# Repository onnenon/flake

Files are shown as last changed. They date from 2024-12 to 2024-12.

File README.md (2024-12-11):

<div align="center">
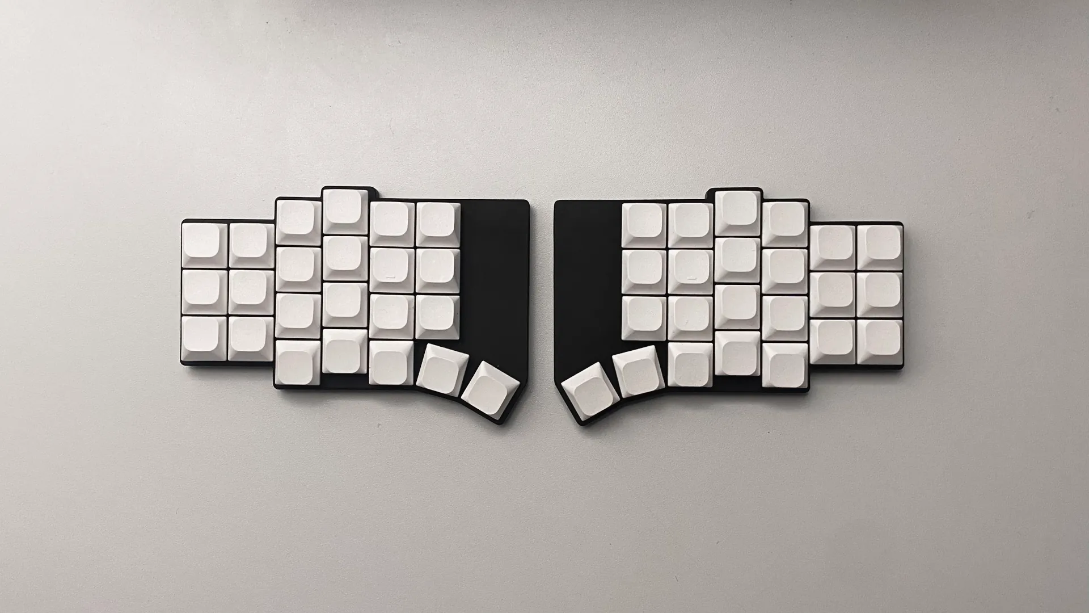
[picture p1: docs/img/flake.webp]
flake image
    
    <h3>Anywhy Flake</h3>
    <p><i>Minimalism, efficiency and comfort</i></p>
</div>

# Why

_To be productive, stay healthy and enjoy the process._

By the 19th century, a need for a faster way of writing had emerged, which led to the invention of typewriters. Two centuries later, modern keyboards don't look much different from their predecessors, even though such design has been proven to be quite inefficient and often harmful.

Addressing these problems leads to huge benefits considering how often people use keyboards in the modern world.

# How

There are several problems that the Flake keyboard solves. I'll describe those with the most significant impact.

## Stagger

If you take your hand and look at the fingers, you can notice that they are positioned horizontally. Now take a look at your keyboard - the keys are grouped in arrays that are shifted vertically, known as row-based stagger.

row-based stagger keyboard image

This well-known layout forces your fingers to move in a counterintuitive way. The solution to that problem is simple: we need to rearrange the keys in a more human-friendly way.

flake stagger image

As you can see, Flake has what's called a column-based stagger. Because of this, keys are located in the path of natural finger movement, which results in a much more pleasant typing experience and reduced fatigue.

## Split

One of the most noticeable things about Flake is that it has two separate halves.

Regular keyboards are made in a single monolithic block, and the main problem is that such a form factor requires our forearms to meet in the center. To compensate for this, wrists are bent apart. This position creates an unnatural angle between the forearm and the wrist, which in the long term will likely lead to constant wrist pain.

Each half of the split keyboard can be rotated and placed in any suitable way so everyone can adapt the setup to their personal preference, avoiding potential damage to the wrists.

As an added bonus, we get free space right between the halves which can be occupied by a trackpad, coffee, or even a cat (=^..^=).

## Keys amount

There's a high chance that some might feel confused seeing such a small number of keys, considering user productivity is one of the priorities for Anywhy.

flake s image

Indeed, Flake has fewer keys than most conventional keyboards (46 keys in total), and that's not a compromise, but a feature. A large number of keys causes hands to move around to reach further-placed keys like digits, brackets, punctuation, Backspace, Escape, etc.

Having fewer keys doesn't mean less functionality. In fact, Flake is not only fully input-compatible with regular keyboards but also allows you to add more keys than most keyboards have.

config showcase image

By default, Flake uses [ZMK Firmware](https://zmk.dev) which provides functionality that significantly increases productivity. One of the most used features, which allows having all possible inputs with a minimal amount of keys, is [layers](https://zmk.dev/docs/keymaps#layers). They are pretty simple and work just like the well-known Shift key.

For those who strive for absolute comfort and compactness, there is also Flake S with 40 keys.

flake s image

The small version lacks one outer column on each of the halves to reduce pinky usage, as it is the weakest of all fingers.

## Thumb cluster

Keyboards are used in various ways, not only for typing text. Most popular tasks require the use of mod keys such as Control, Alt/Option, Super/Command/Win, and of course, Shift. Even though these keys are regularly used, they are placed in ridiculously inconvenient spots where only the pinky can reach them, and as we already know, it's the weakest finger.

The Flake keyboard has a so-called thumb cluster which contains 10 keys in total to address that problem. In contrast, the thumb is one of the strongest fingers and is ideal for holding mod keys.

# What

Flake supports both wired and wireless (Bluetooth) connection, which makes it perfect for both home usage with a PC or portable setup with a laptop, tablet, or even smartphone.

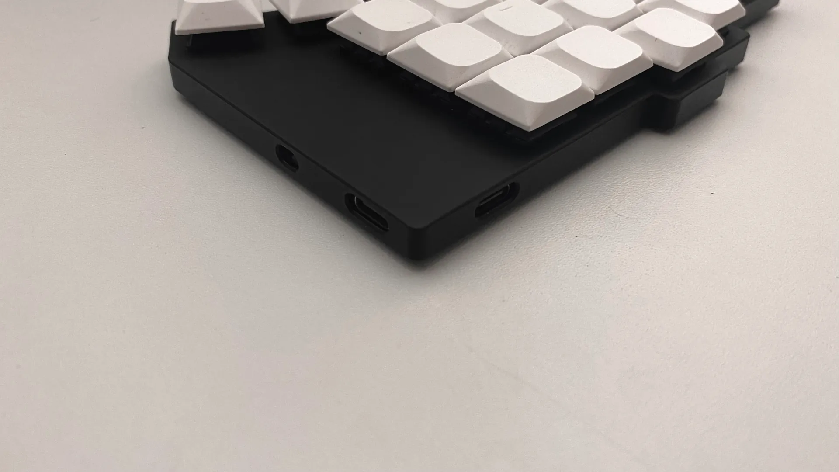
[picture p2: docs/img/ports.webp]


To achieve both types of connectivity, each half has two USB-C ports, one on the top and one on the inner side. The side port is used to connect the halves together, and then one of them (usually the left one) can be connected to any device using the top port, which is also used to charge the keyboard.

> Ports on the side are used only to communicate with each other, so they can't be used to charge the keyboard or to flash the new firmware
> 
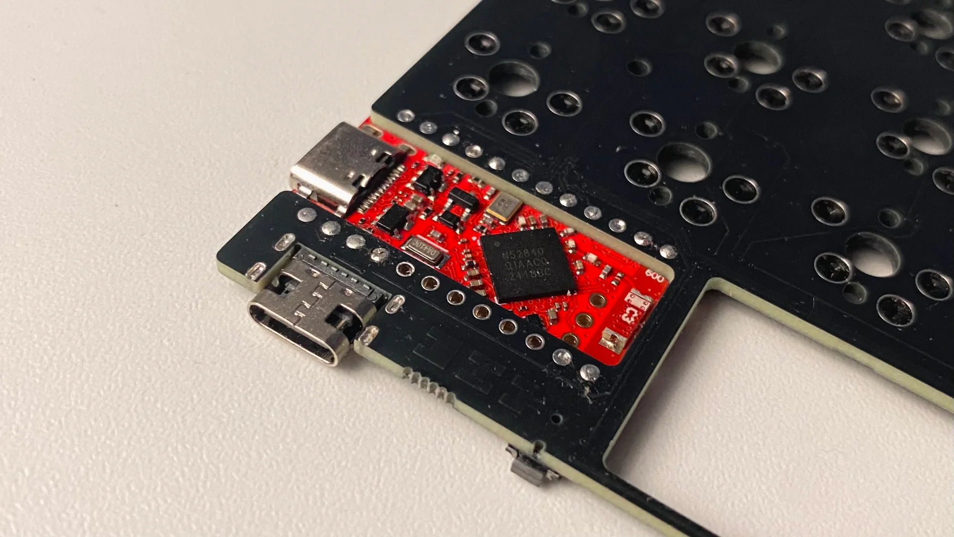
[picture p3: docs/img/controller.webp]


Flake is extremely thin. The keyboard body without switches and feet is a bit less than 0.8cm in height, which makes it compact and really comfortable to use, especially with low-profile switches.

> Unfortunately, to achieve such a low height, some tradeoffs were made in PCB and enclosure designs that make assembly and soldering a bit tricky. There's a chance that the keyboard will become thicker in the future if it will make it more robust and easier to repair.

Talking about switches, Flake is hot-swappable and supports three types of switches: the well-known Cherry MX compatible switches, low-profile Kailh Choc V1, and their newer version Choc V2.

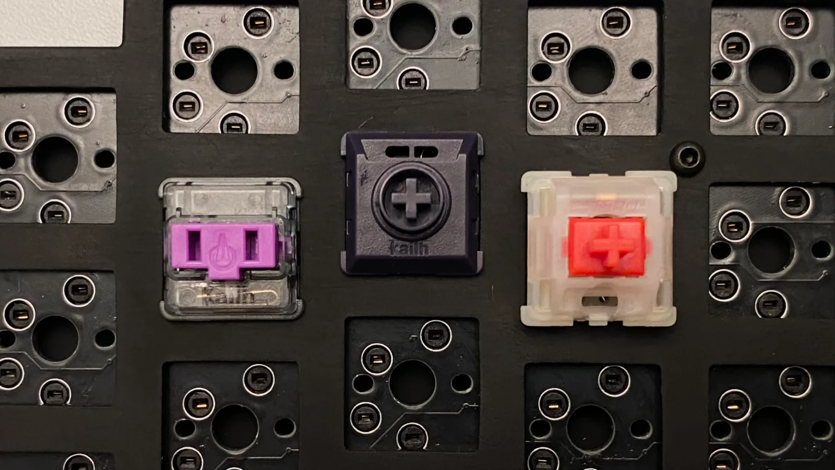
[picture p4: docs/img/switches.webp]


In order to use MX Switches, the special "plate" comes with the Flake which should be placed between the board and the switches.

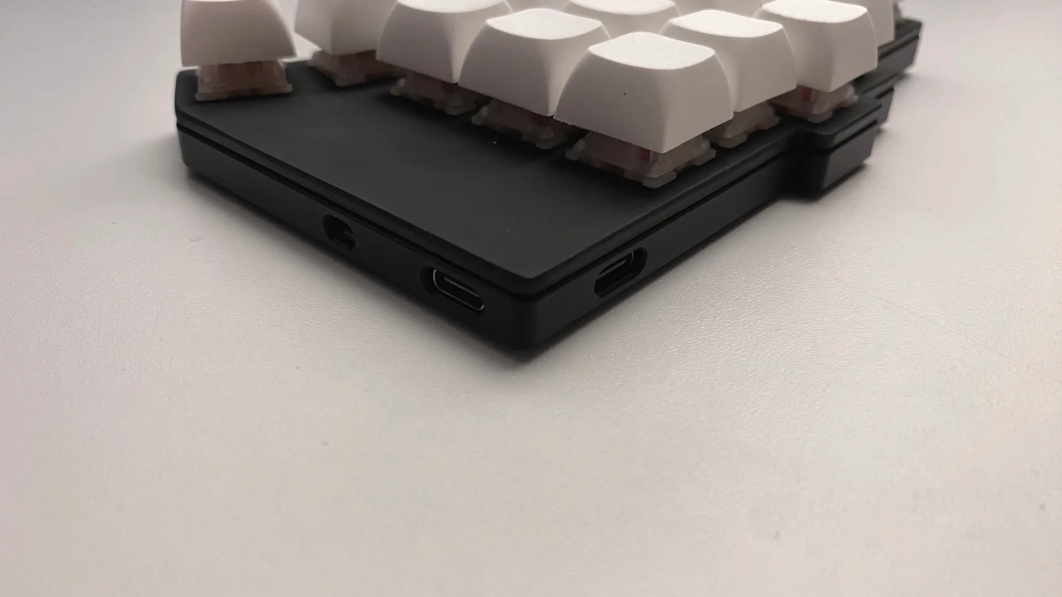
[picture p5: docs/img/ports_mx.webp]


> Plates are not required for the Choc switches as they are much lower than MX switches and don't need additional enclosure height to securely sit in the board

Anywhy Flake v0.1.0 is fully the tested version. The most similar version this repo has is v0.1.1, where I've changed the silkscreen modified some edges, and also added PCB copper fill. So if you want to build Flake yourself, I recommend using the v0.1.1 version, as well as checking out the [build guide](/docs/build_guide.md)

> Feel free to send me your builds and keyboard reviews :)

# Credits

Huge thanks to:

- [@foostan](https://github.com/foostan), the author of [Corne Keyboard](https://github.com/foostan/crkbd) which was my introduction to the world of ergonomic keyboards.
  
- [@pashutk](https://github.com/pashutk), the author of [Chocofi](https://github.com/pashutk/chocofi), an amazing tiny keyboard I've been using for a while.
  
- [@josefadamcik](https://github.com/josefadamcik), the author of [Sofle](https://github.com/josefadamcik/SofleKeyboard) which gave huge inspiration for the Flake's key layout.
  
- [@petejohanson](https://github.com/petejohanson) for creating [ZMK Firmware](https://github.com/zmkfirmware/zmk) and all the [contributors](https://github.com/zmkfirmware/zmk/graphs/contributors) that make it better each day.

- Everyone working on [KiCad](https://gitlab.com/kicad/code/kicad) and [FreeCAD](https://github.com/FreeCAD/FreeCAD), for creating such powerful open source tools

- People from the [ZMK discord server](https://zmk.dev/community/discord/invite) for being so kind while helping me learn how to design PCB and how to debug and solve various problems.

- Finally, a huge thank you to everyone who explores unpopular technologies, digs into niche topics, and makes amazing things possible.

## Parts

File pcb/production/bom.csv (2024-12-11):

Designator | Footprint | Quantity | Value | LCSC Part #
_16, _15, _14, _13, _12, _11, _10, _9, _8, _7, _6, _5, _4, _3, _2, |  | 16
BT1, BT2 | JST_1.25mm_mid-mount | 2 | Battery
D1, D10, D11, D12, D13, D14, D15, D16, D17, D18, D19, D2, D20, D21, D22, D23, D24, D25, D26, D27, D28, D29, D3, D30, D31, D32, D33, D34, D35, D36, D37, D38, D39, D4, D40, D41, D42, D43, D44, D45, D46, D5, D6, D7, D8, D9 | D_SOD-123_Handsoldering | 46 | D
J1, J2 | USB-C_6Pin_Mid-mount | 2 | USB_C_Receptacle_PowerOnly_6P
RSW1, RSW2 | TS-1289VE-4 | 2 | Reset_SW
SW1, SW10, SW11, SW12, SW13, SW14, SW15, SW16, SW17, SW18, SW19, SW2, SW20, SW21, SW22, SW23, SW24, SW25, SW26, SW27, SW28, SW29, SW3, SW30, SW31, SW32, SW33, SW34, SW35, SW36, SW37, SW38, SW39, SW4, SW40, SW41, SW42, SW43, SW44, SW45, SW46, SW5, SW6, SW7, SW8, SW9 | SW_MX_Choc-v1v2_Hotswap | 46 | SW_Push
U1, U2 | ProMicro_SMD | 2 | ProMicro

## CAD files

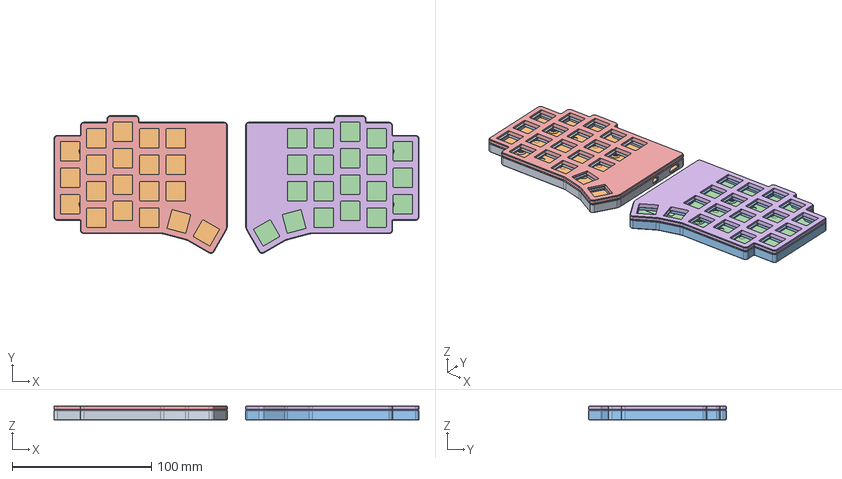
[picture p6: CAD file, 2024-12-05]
enclosure/40keys/Enclosure-S.FCStd
262.0 x 99.0 x 10.4 mm
Top
Bottom
Top-Mirrored
Bottom-Mirrored
Plate
Plate-Mirrored

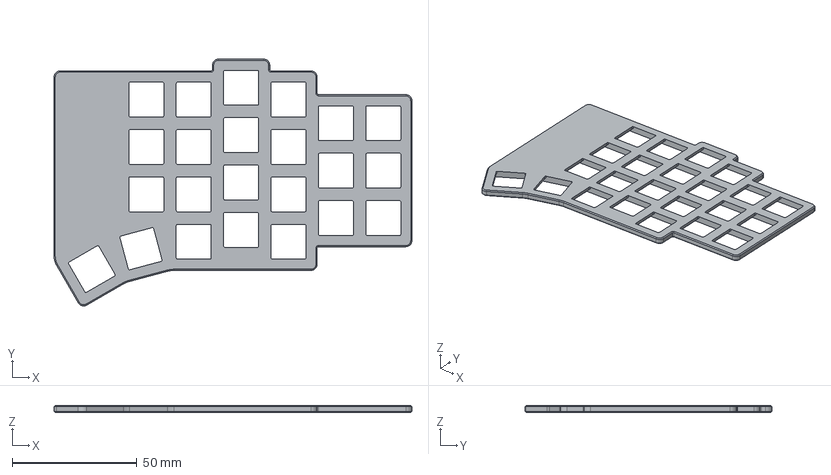
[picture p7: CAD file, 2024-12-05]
enclosure/46keys/Enclosure-Plate-Mirrored.step
143.5 x 99.0 x 3.00 mm

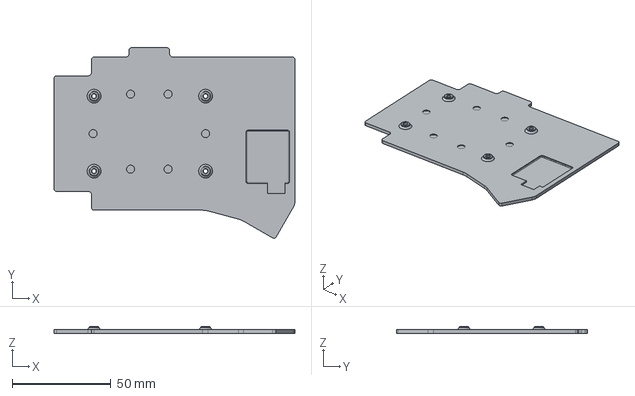
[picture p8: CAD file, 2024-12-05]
enclosure/40keys/Enclosure-S-Bottom.step
122.1 x 96.6 x 3.30 mm

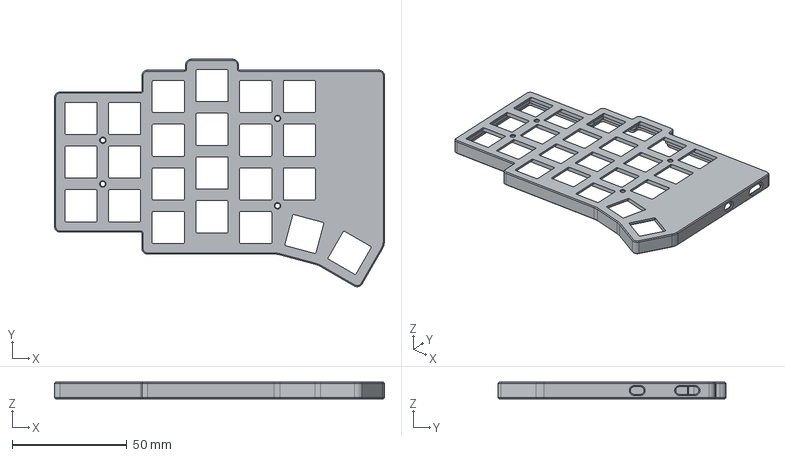
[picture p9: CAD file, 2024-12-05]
enclosure/46keys/Enclosure-Top.step
143.5 x 99.0 x 7.30 mm

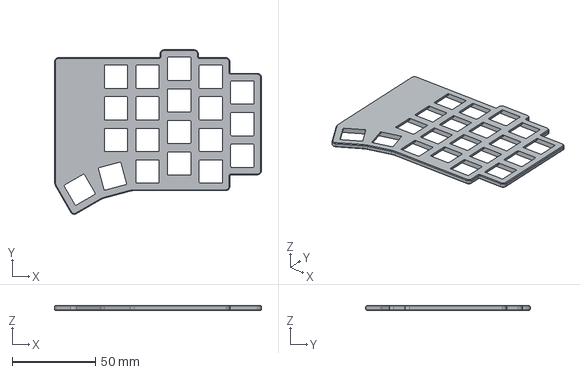
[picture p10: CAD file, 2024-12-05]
enclosure/40keys/Enclosure-S-Plate-Mirrored.step
124.5 x 99.0 x 3.00 mm

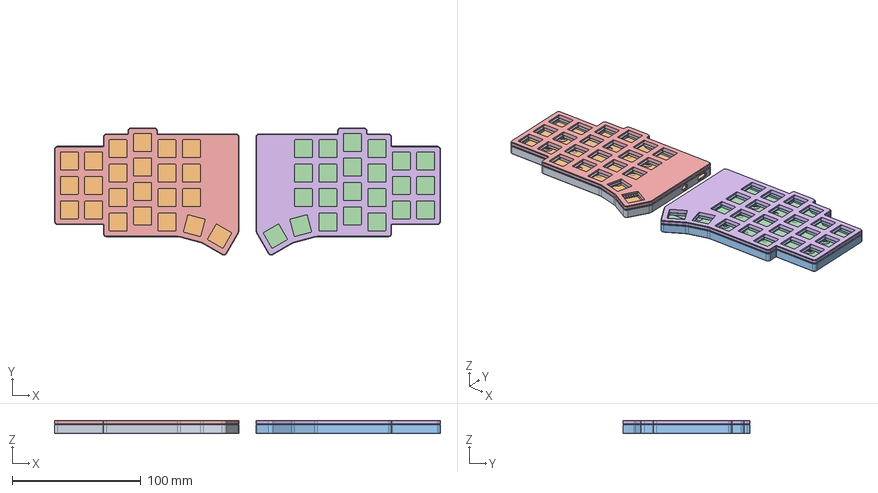
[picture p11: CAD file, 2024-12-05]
enclosure/46keys/Enclosure.FCStd
300.0 x 99.0 x 10.4 mm
Top
Bottom
Top-Mirrored
Bottom-Mirrored
Plate
Plate-Mirrored

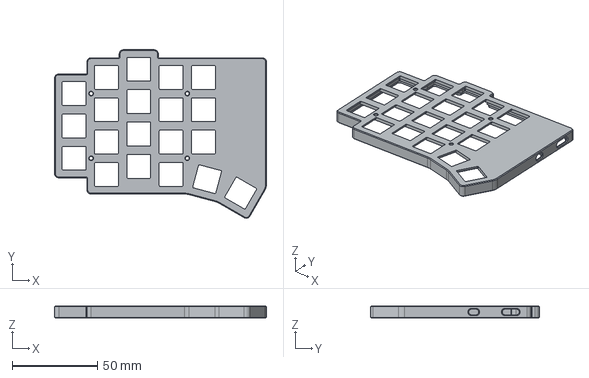
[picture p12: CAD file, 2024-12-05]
enclosure/40keys/Enclosure-S-Top.step
124.5 x 99.0 x 7.30 mm

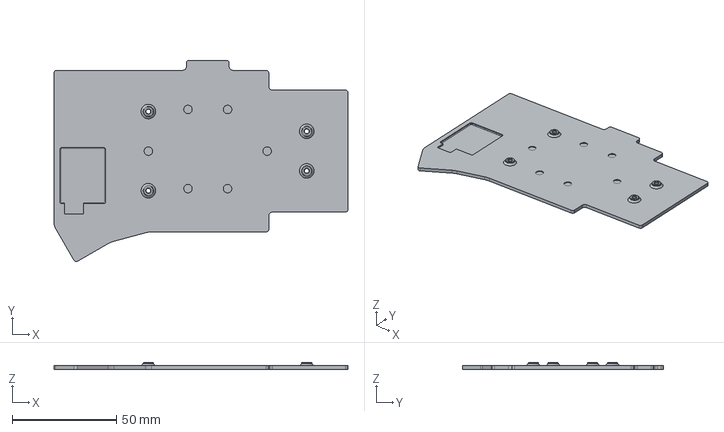
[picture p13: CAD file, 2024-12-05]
enclosure/46keys/Enclosure-Bottom-Mirrored.step
141.1 x 96.6 x 3.30 mm

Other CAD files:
enclosure/46keys/Enclosure-Plate.step
enclosure/40keys/Enclosure-S-Plate.step
enclosure/40keys/Enclosure-S-Top-Mirrored.step
enclosure/46keys/Enclosure-Top-Mirrored.step
enclosure/40keys/Enclosure-S-Bottom-Mirrored.step
enclosure/46keys/Enclosure-Bottom.step

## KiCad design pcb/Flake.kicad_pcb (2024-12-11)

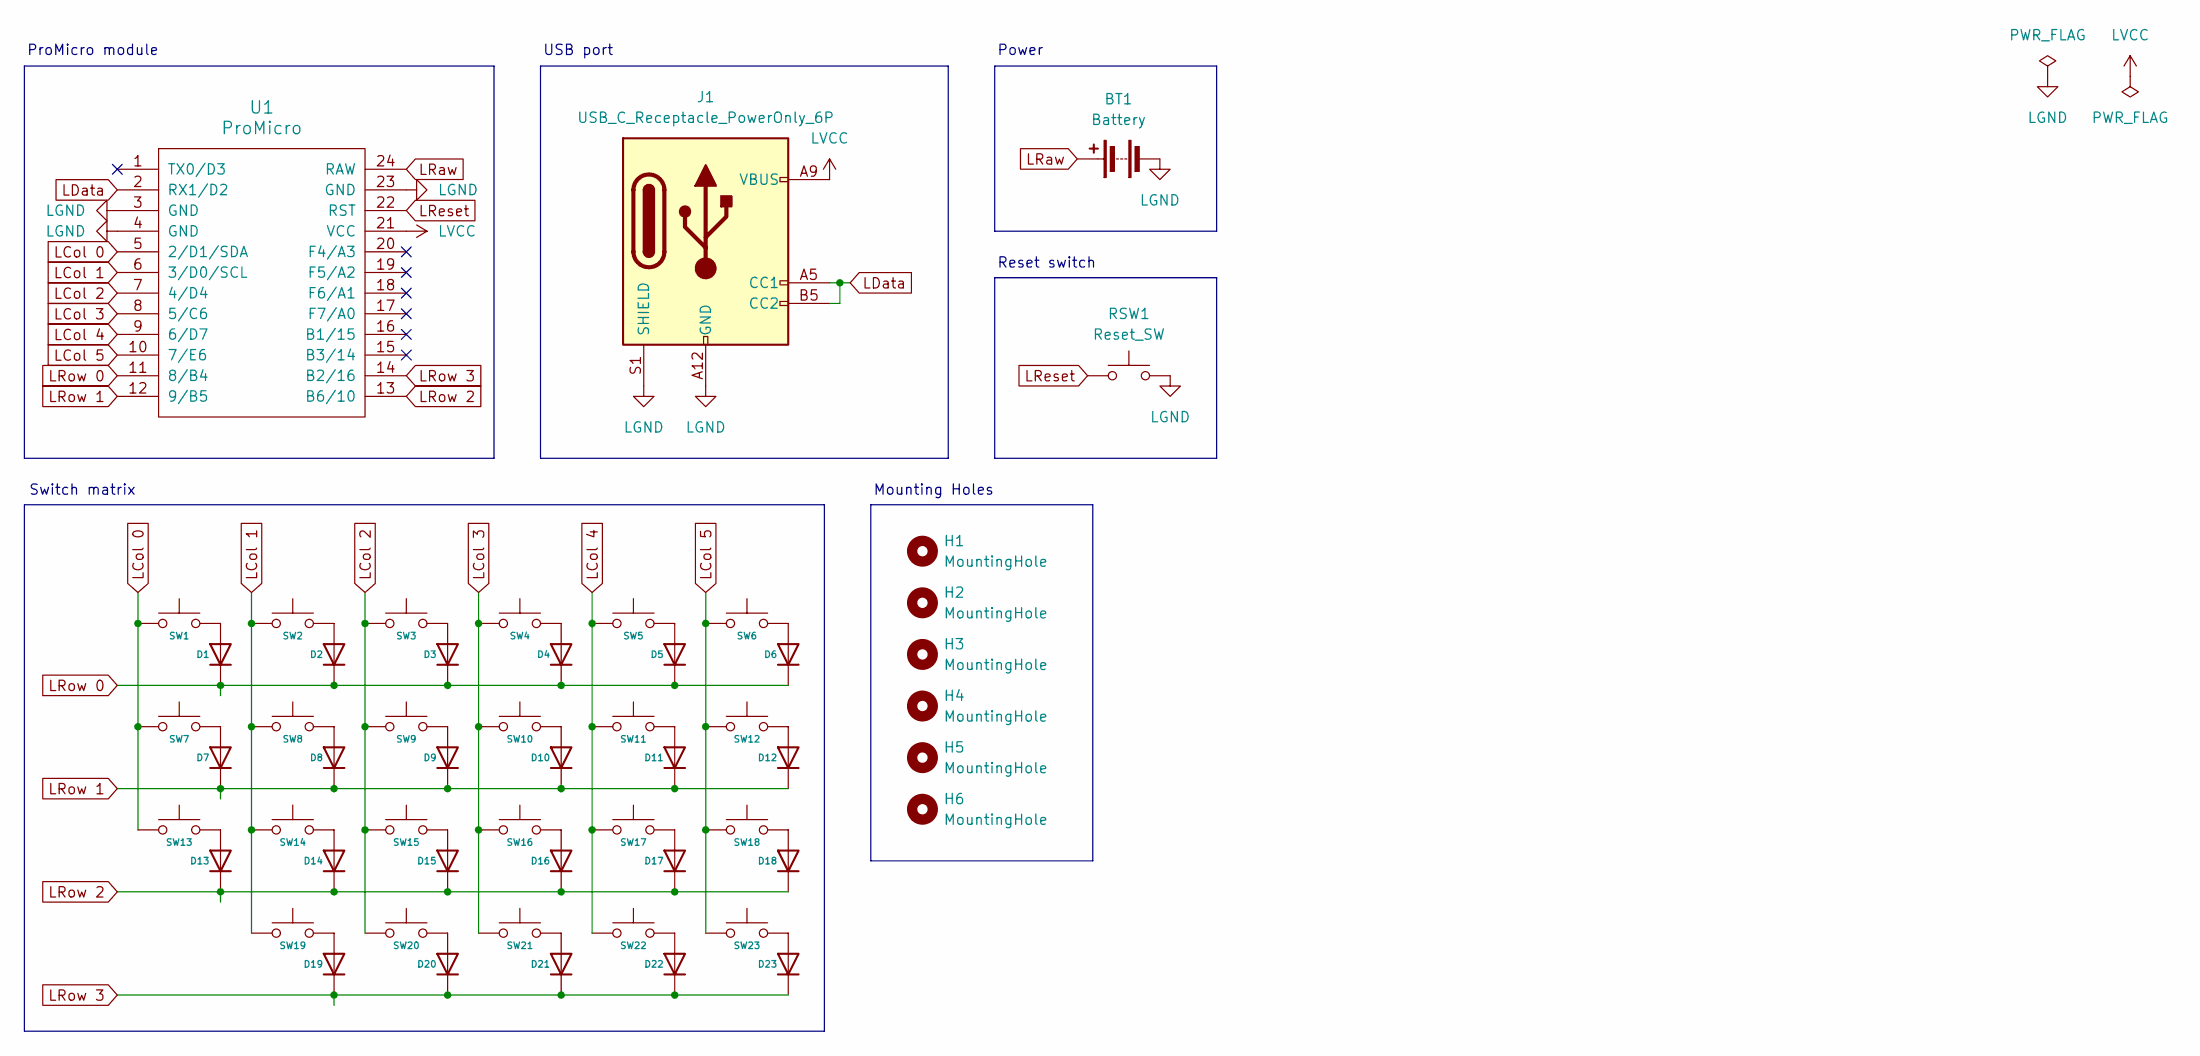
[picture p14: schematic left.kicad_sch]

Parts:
BT1: Battery; JST_1.25mm_mid-mount
D1, D2, D3, D4, D5, D6, D7, D8, D9, D10, D11, D12, D13, D14, D15, D16, D17, D18, D19, D20, D21, D22, D23: D; D_SOD-123_Handsoldering
H1, H2, H3, H4, H5, H6: MountingHole; MountingHole_2.2mm_M2
J1: USB_C_Receptacle_PowerOnly_6P; USB-C_6Pin_Mid-mount
RSW1: Reset_SW; TS-1289VE-4
SW1, SW2, SW3, SW4, SW5, SW6, SW7, SW8, SW9, SW10, SW11, SW12, SW13, SW14, SW15, SW16, SW17, SW18, SW19, SW20, SW21, SW22, SW23: SW_Push; SW_MX_Choc-v1v2_Hotswap
U1: ProMicro; ProMicro_SMD

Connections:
LCol 0: SW1.1, SW7.1, SW13.1, U1.5 (2/D1/SDA)
LCol 1: SW2.1, SW8.1, SW14.1, SW19.1, U1.6 (3/D0/SCL)
LCol 2: SW3.1, SW9.1, SW15.1, SW20.1, U1.7 (4/D4)
LCol 3: SW4.1, SW10.1, SW16.1, SW21.1, U1.8 (5/C6)
LCol 4: SW5.1, SW11.1, SW17.1, SW22.1, U1.9 (6/D7)
LCol 5: SW6.1, SW12.1, SW18.1, SW23.1, U1.10 (7/E6)
LData: J1.A5 (CC1), J1.B5 (CC2), U1.2 (RX1/D2)
LGND: BT1.2 (-), J1.A12 (GND), J1.B12 (GND), J1.S1 (SHIELD), RSW1.2, U1.3 (GND), U1.4 (GND), U1.23 (GND)
LRaw: BT1.1 (+), U1.24 (RAW)
LReset: RSW1.1, U1.22 (RST)
LRow 0: D1.1 (K), D2.1 (K), D3.1 (K), D4.1 (K), D5.1 (K), D6.1 (K), U1.11 (8/B4)
LRow 1: D7.1 (K), D8.1 (K), D9.1 (K), D10.1 (K), D11.1 (K), D12.1 (K), U1.12 (9/B5)
LRow 2: D13.1 (K), D14.1 (K), D15.1 (K), D16.1 (K), D17.1 (K), D18.1 (K), U1.13 (B6/10)
LRow 3: D19.1 (K), D20.1 (K), D21.1 (K), D22.1 (K), D23.1 (K), U1.14 (B2/16)
LVCC: J1.A9 (VBUS), J1.B9 (VBUS), U1.21 (VCC)
unnamed: D1.2 (A), SW1.2
unnamed: D2.2 (A), SW2.2
unnamed: D3.2 (A), SW3.2
unnamed: D4.2 (A), SW4.2
unnamed: D5.2 (A), SW5.2
unnamed: D6.2 (A), SW6.2
unnamed: D7.2 (A), SW7.2
unnamed: D8.2 (A), SW8.2
unnamed: D9.2 (A), SW9.2
unnamed: D10.2 (A), SW10.2
unnamed: D11.2 (A), SW11.2
unnamed: D12.2 (A), SW12.2
unnamed: D13.2 (A), SW13.2
unnamed: D14.2 (A), SW14.2
unnamed: D15.2 (A), SW15.2
unnamed: D16.2 (A), SW16.2
unnamed: D17.2 (A), SW17.2
unnamed: D18.2 (A), SW18.2
unnamed: D19.2 (A), SW19.2
unnamed: D20.2 (A), SW20.2
unnamed: D21.2 (A), SW21.2
unnamed: D22.2 (A), SW22.2
unnamed: D23.2 (A), SW23.2

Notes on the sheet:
Switch matrix
Mounting Holes
USB port
Power
ProMicro module
Reset switch

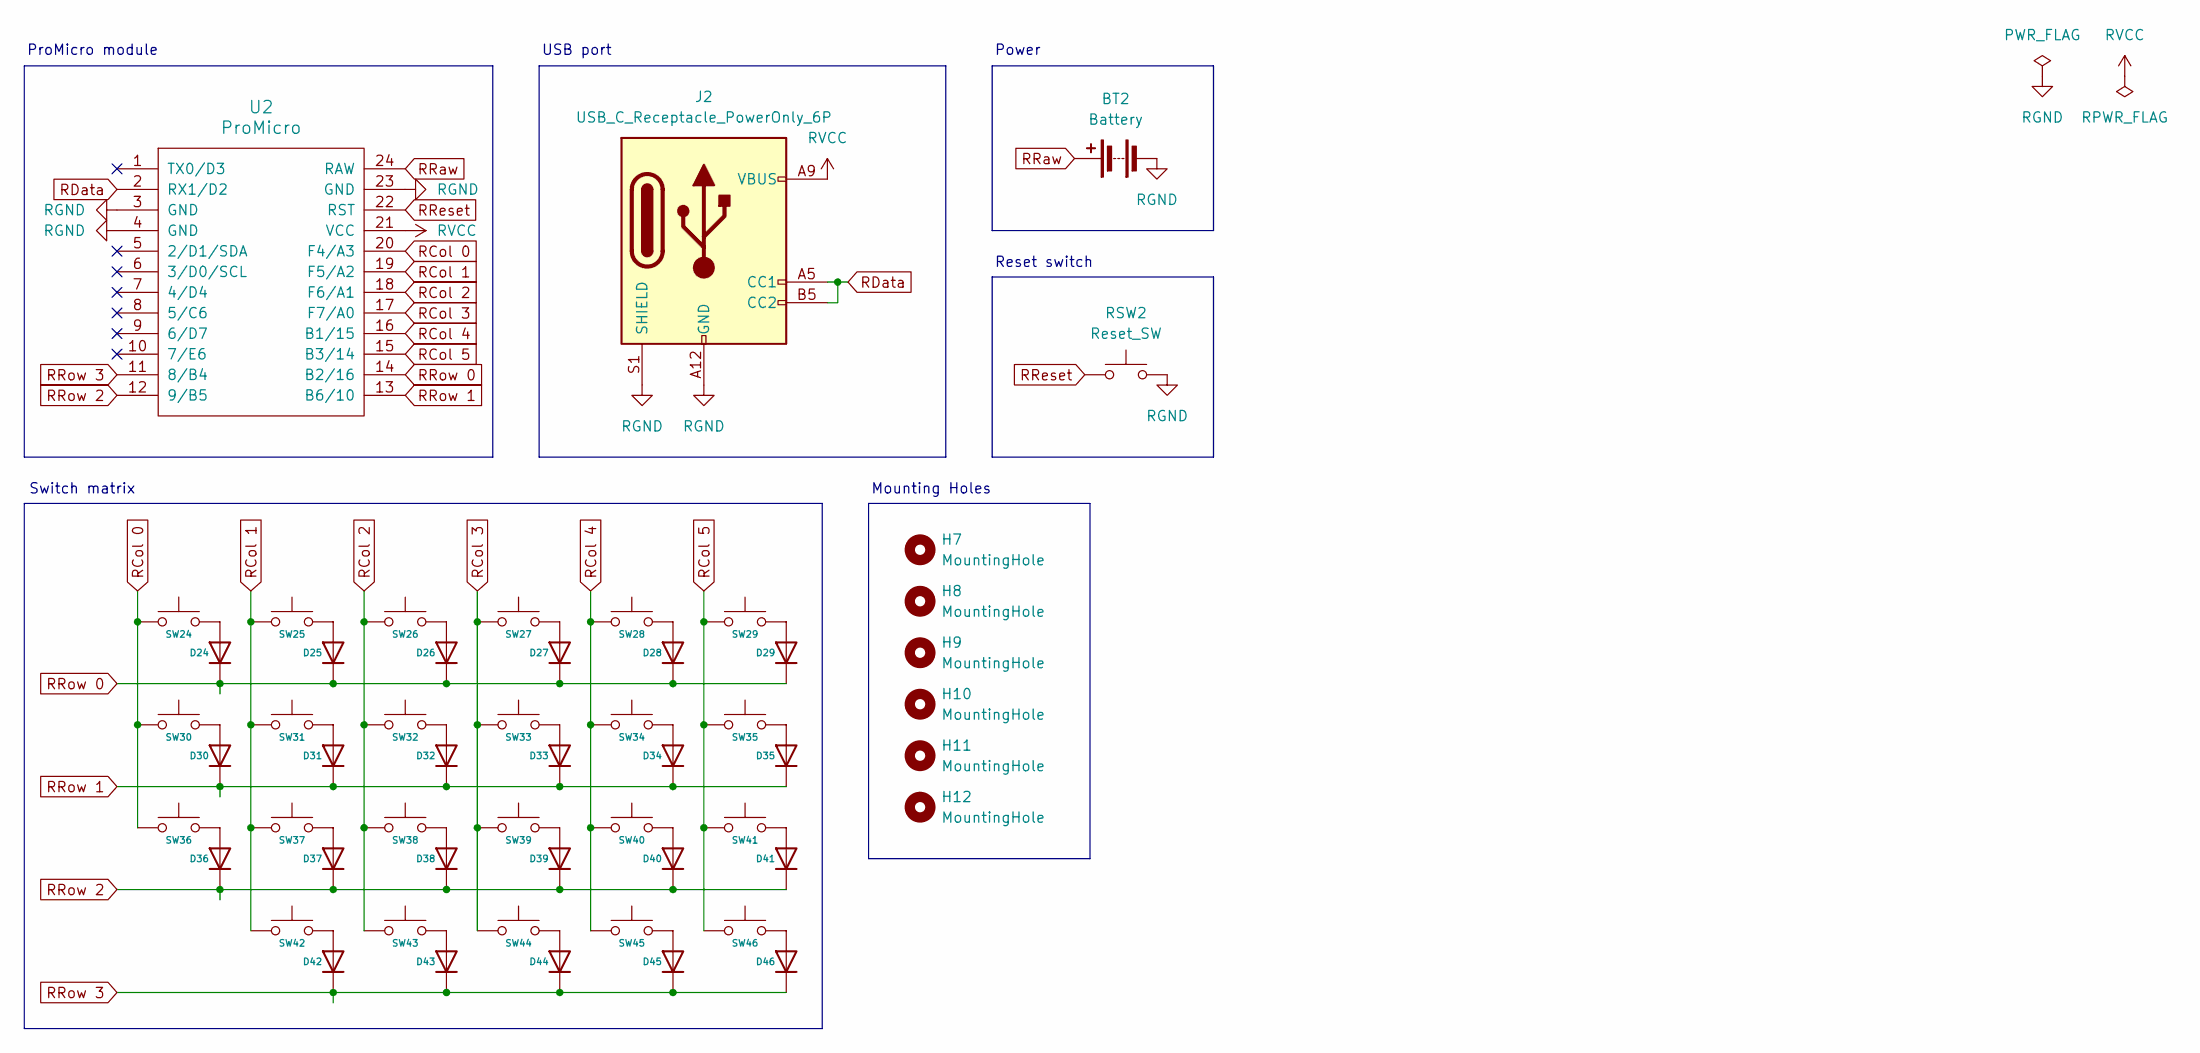
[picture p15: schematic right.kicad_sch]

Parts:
BT2: Battery; JST_1.25mm_mid-mount
D24, D25, D26, D27, D28, D29, D30, D31, D32, D33, D34, D35, D36, D37, D38, D39, D40, D41, D42, D43, D44, D45, D46: D; D_SOD-123_Handsoldering
H7, H8, H9, H10, H11, H12: MountingHole; MountingHole_2.2mm_M2
J2: USB_C_Receptacle_PowerOnly_6P; USB-C_6Pin_Mid-mount
RSW2: Reset_SW; TS-1289VE-4
SW24, SW25, SW26, SW27, SW28, SW29, SW30, SW31, SW32, SW33, SW34, SW35, SW36, SW37, SW38, SW39, SW40, SW41, SW42, SW43, SW44, SW45, SW46: SW_Push; SW_MX_Choc-v1v2_Hotswap
U2: ProMicro; ProMicro_SMD

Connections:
unnamed: D24.2 (A), SW24.2
unnamed: D25.2 (A), SW25.2
unnamed: D26.2 (A), SW26.2
unnamed: D27.2 (A), SW27.2
unnamed: D28.2 (A), SW28.2
unnamed: D29.2 (A), SW29.2
unnamed: D30.2 (A), SW30.2
unnamed: D31.2 (A), SW31.2
unnamed: D32.2 (A), SW32.2
unnamed: D33.2 (A), SW33.2
unnamed: D34.2 (A), SW34.2
unnamed: D35.2 (A), SW35.2
unnamed: D36.2 (A), SW36.2
unnamed: D37.2 (A), SW37.2
unnamed: D38.2 (A), SW38.2
unnamed: D39.2 (A), SW39.2
unnamed: D40.2 (A), SW40.2
unnamed: D41.2 (A), SW41.2
unnamed: D42.2 (A), SW42.2
unnamed: D43.2 (A), SW43.2
unnamed: D44.2 (A), SW44.2
unnamed: D45.2 (A), SW45.2
unnamed: D46.2 (A), SW46.2
RCol 0: SW24.1, SW30.1, SW36.1, U2.20 (F4/A3)
RCol 1: SW25.1, SW31.1, SW37.1, SW42.1, U2.19 (F5/A2)
RCol 2: SW26.1, SW32.1, SW38.1, SW43.1, U2.18 (F6/A1)
RCol 3: SW27.1, SW33.1, SW39.1, SW44.1, U2.17 (F7/A0)
RCol 4: SW28.1, SW34.1, SW40.1, SW45.1, U2.16 (B1/15)
RCol 5: SW29.1, SW35.1, SW41.1, SW46.1, U2.15 (B3/14)
RData: J2.A5 (CC1), J2.B5 (CC2), U2.2 (RX1/D2)
RGND: BT2.2 (-), J2.A12 (GND), J2.B12 (GND), J2.S1 (SHIELD), RSW2.2, U2.3 (GND), U2.4 (GND), U2.23 (GND)
RRaw: BT2.1 (+), U2.24 (RAW)
RReset: RSW2.1, U2.22 (RST)
RRow 0: D24.1 (K), D25.1 (K), D26.1 (K), D27.1 (K), D28.1 (K), D29.1 (K), U2.14 (B2/16)
RRow 1: D30.1 (K), D31.1 (K), D32.1 (K), D33.1 (K), D34.1 (K), D35.1 (K), U2.13 (B6/10)
RRow 2: D36.1 (K), D37.1 (K), D38.1 (K), D39.1 (K), D40.1 (K), D41.1 (K), U2.12 (9/B5)
RRow 3: D42.1 (K), D43.1 (K), D44.1 (K), D45.1 (K), D46.1 (K), U2.11 (8/B4)
RVCC: J2.A9 (VBUS), J2.B9 (VBUS), U2.21 (VCC)

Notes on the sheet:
Switch matrix
Mounting Holes
USB port
Power
ProMicro module
Reset switch

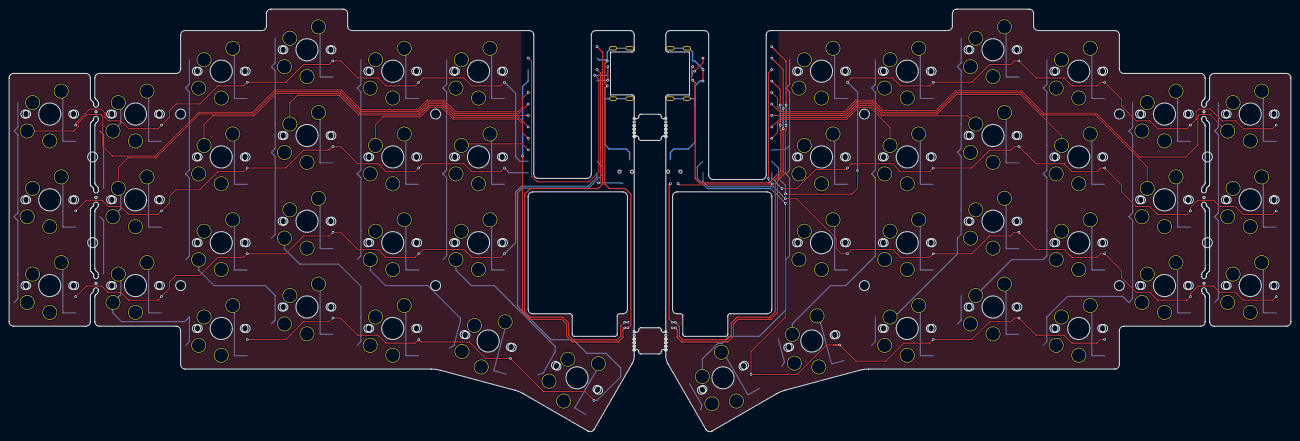
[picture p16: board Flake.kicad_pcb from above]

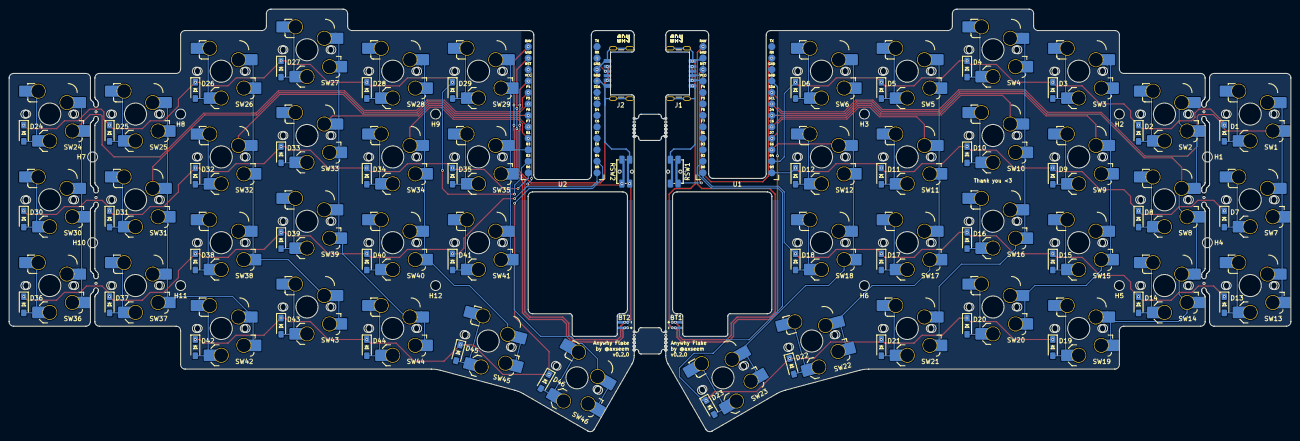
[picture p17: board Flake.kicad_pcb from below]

Board: 2 copper layers, 284.0 x 93.6 mm, 112 parts (64 on the bottom side), 76 nets.

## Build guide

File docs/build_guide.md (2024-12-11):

# How to build the Flake?

## Components

To build the flake you need the following materials

| Name | Count | Remarks |
|:---|:---|:---|
| PCB | 1 set | |
| MX hot-swap sockets | 40/46 | |
| Choc hot-swap sockets | 40/46 | |
| Diodes | 40/46 | 1N4148W SOD-123 |
| Switches | 40/46 | Choc V1/V2 or MX switches |
| Keycaps | 40/46 | Compatible with your switches |
| Controllers | 2 | Any ProMicro compatible controller (nice!nano for instance) |
| USB-C ports | 2 | Mid-mount with 6 pins |
| Reset buttons | 2 | TS-1289VE-4 |
| Enclosure | 1 set | |
| Plates | 1 set | Required if you want to use MX switches |
| M2 Screws | 8 | 7mm length (8mm should work too, but will stick out) |
| M2 Hex nuts | 8 | |
| Rubber feats | 8 | 6x2mm |
| Battery sockets | 2 | JST 1.25 with the straight needle |
| Batteries | 2 | 402025 with JST 1.25 (302025 should work too) |

> If you don't plan to use MX switches, you can skip the plates. If you will be using the keyboard only in wired mode, batteries can be skipped too.

## Build process

The first iterations of the PCB were not designed with ease of hand soldering in mind. It's definitely possible, as I've done one PCB myself, but the process was actually frustrating. I'm currently working on a new version of the PCB that will hopefully be much easier to solder with an iron.

But if you're confident enough in your soldering skills, you should be able to figure out how to assemble the PCB v0.1.1. The advice I can give is to place the 1/4 of the controller's legs into the controller's mounting holes and solder it that way. Using just solder without anything inside resulted in poor pin connections for me.

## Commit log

2024-12-08 docs: add bill of materials
    [Flake.kicad_pcb, left.kicad_sch, right.kicad_sch]
2024-12-11 pcb: smd controller footprint
    use smd prom-micro footprint
    easier to break off the last column
    wider controller cutout
    ground usb shield
    reroute some paths
    minimse a chance of damaging the pcb after brakeing off the pinky column
    edit silkscreen
    [Flake.kicad_pcb, bom.csv, designators.csv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]
2024-12-11 docs: warning about soldering difficulties
